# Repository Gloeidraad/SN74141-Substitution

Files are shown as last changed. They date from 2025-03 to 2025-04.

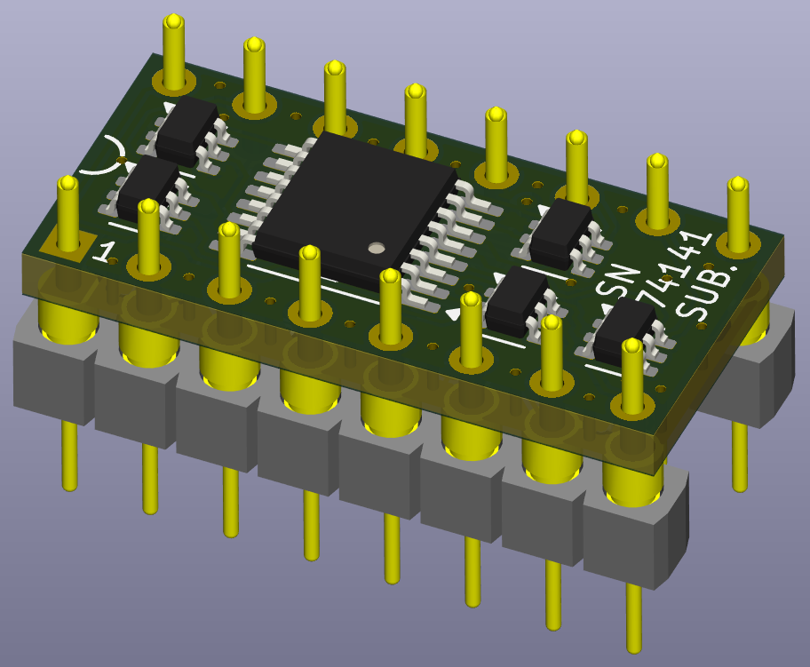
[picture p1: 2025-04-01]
Doc/3d.png

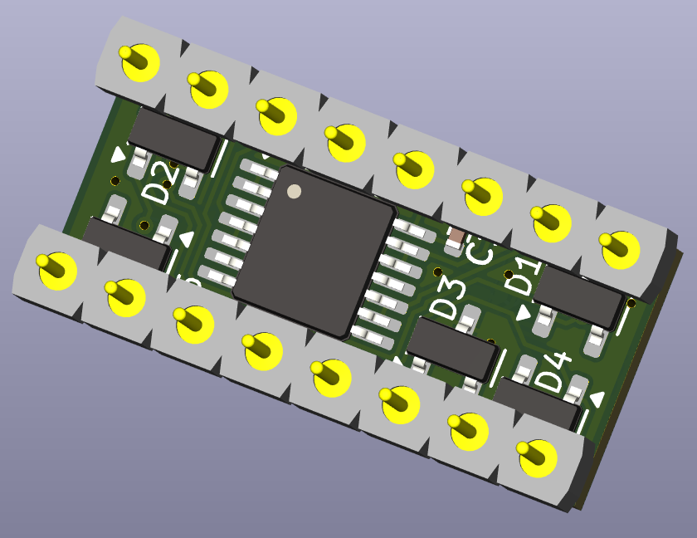
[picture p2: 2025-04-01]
Doc/3d-bot.png

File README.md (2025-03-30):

The SN74141 is an obsolete device intended for diving nixie tubes. However, even today, enthusiasts still love nixie tubes. Sometimes by building digital clocks with nixies, but also keeping vintage equivalent alive. In the old days, very often the nixie tubes are driven by the good old SN74141 device. These devices (or the soviet K155ID1) can still be found on the internet, but stocks are dwindling. I tried to make a replacement circuit which should fit on the location of the original DIL-16 footprint of the SN74141. 

Because of the limited size of the DIL-16 socket, I had to use the smallest devices possible, so if you want to use the design, be sure you are capable to solder TSSOP devices.

The design is not implement on a real PCBA yet, so please test it yourself before placing it in al valuable instrument.

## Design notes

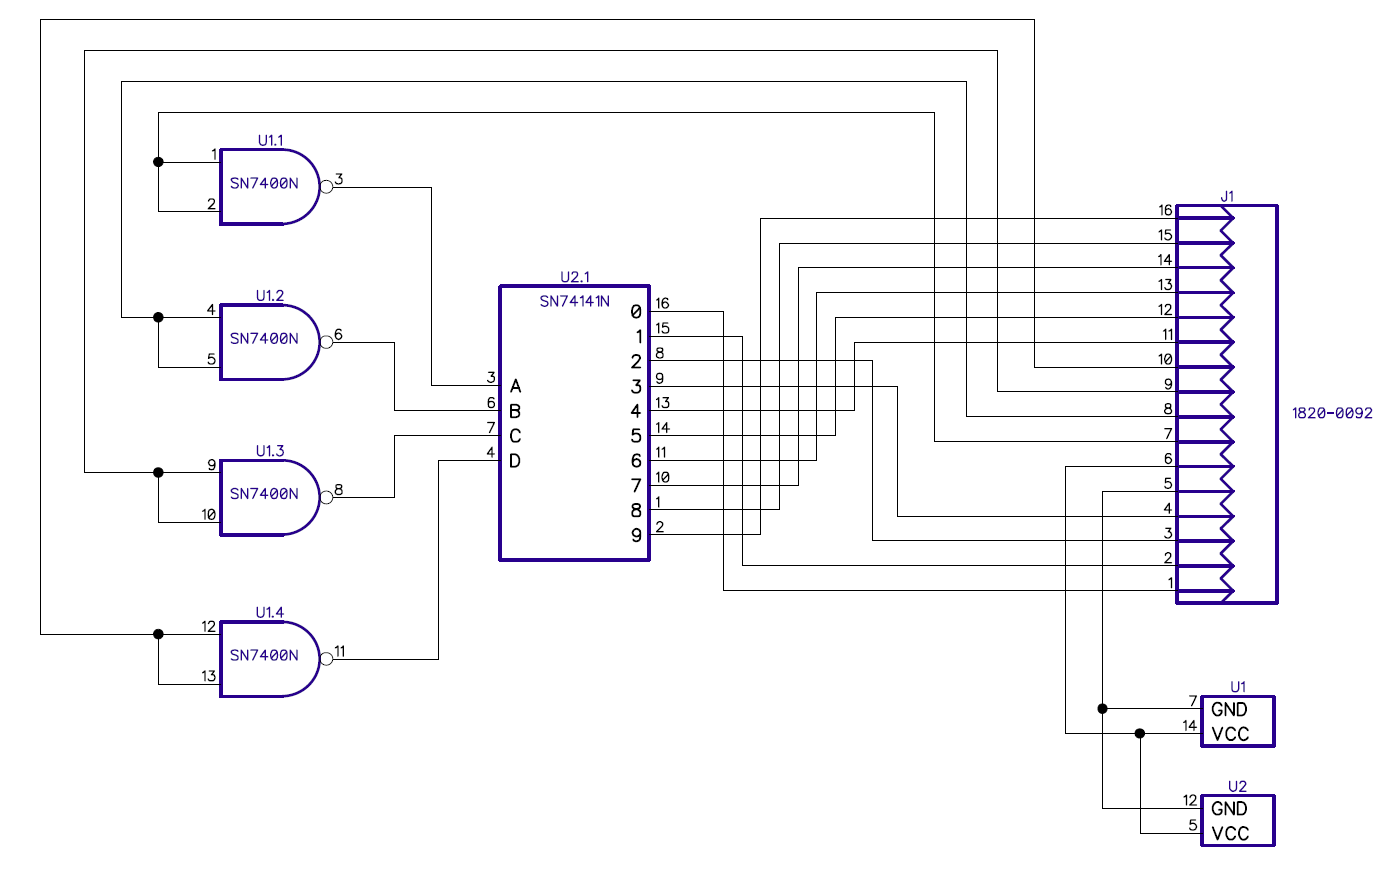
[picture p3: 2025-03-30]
Doc/Schematic 1820-0092.png

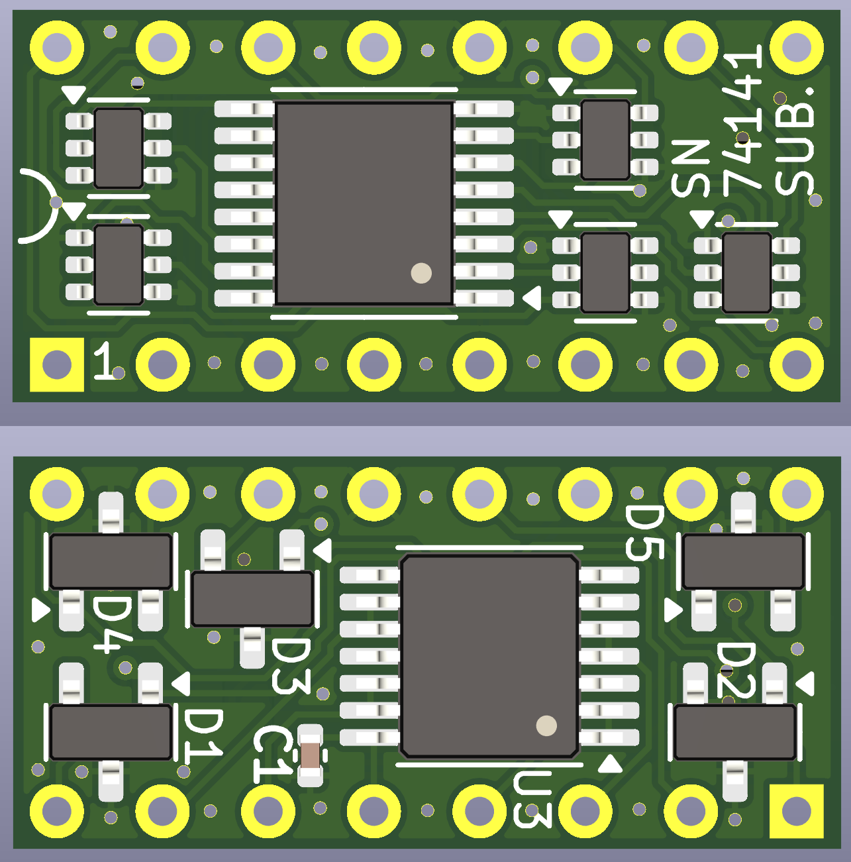
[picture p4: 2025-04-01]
Doc/PCB-V2.png

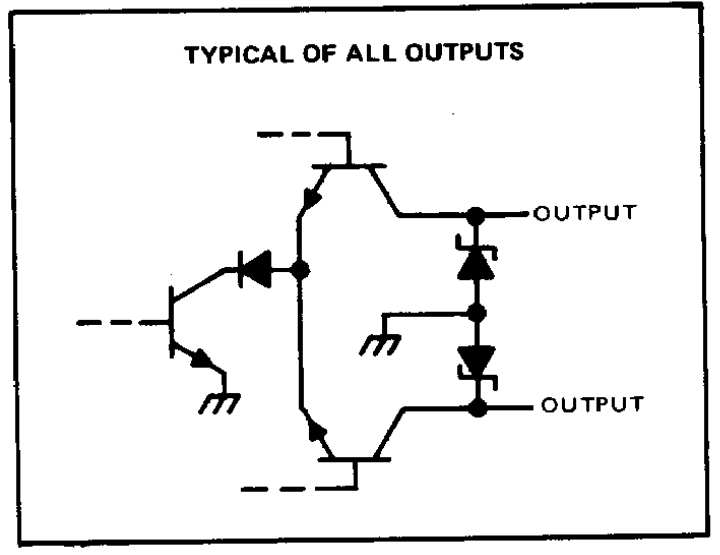
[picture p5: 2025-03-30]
Doc/74141-output.png

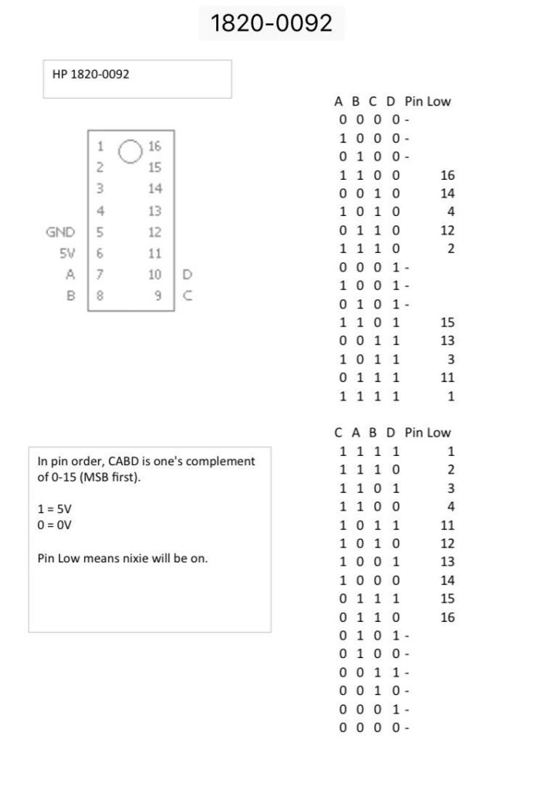
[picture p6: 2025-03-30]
Doc/1820-0092_pins-705x1024.jpg

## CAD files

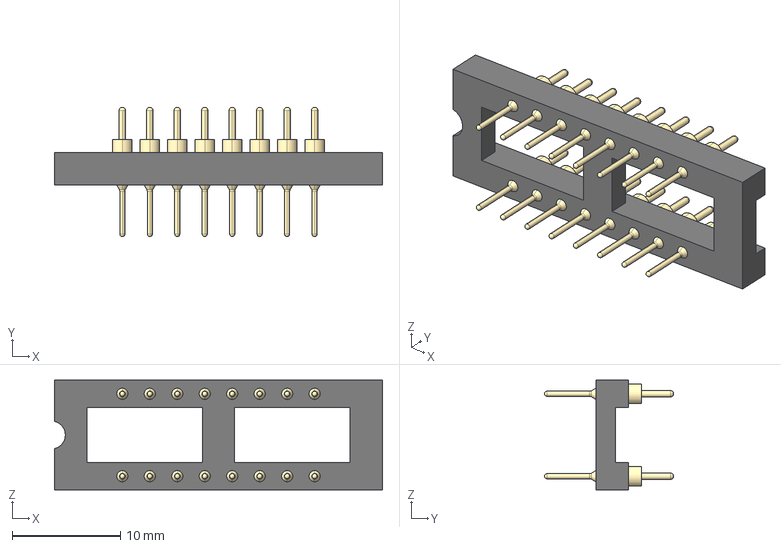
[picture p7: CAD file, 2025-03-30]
Doc/ar_16-st_t.stp
30.3 x 12.0 x 10.2 mm

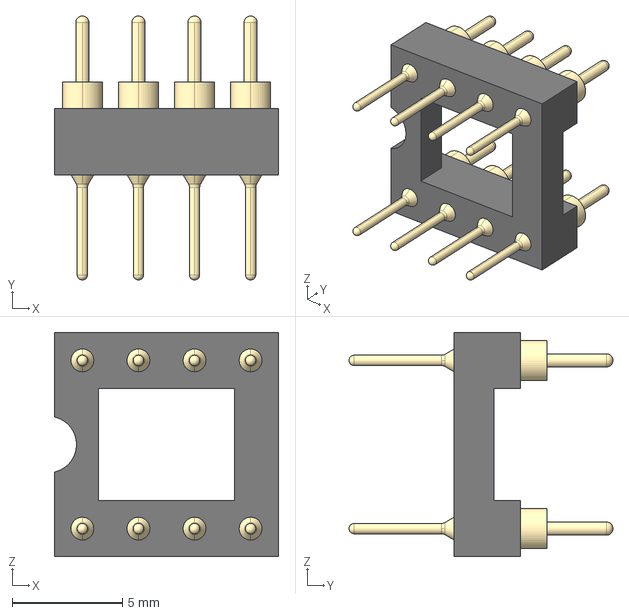
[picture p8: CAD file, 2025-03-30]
Doc/ar_08-st_t.stp
10.2 x 12.0 x 10.2 mm

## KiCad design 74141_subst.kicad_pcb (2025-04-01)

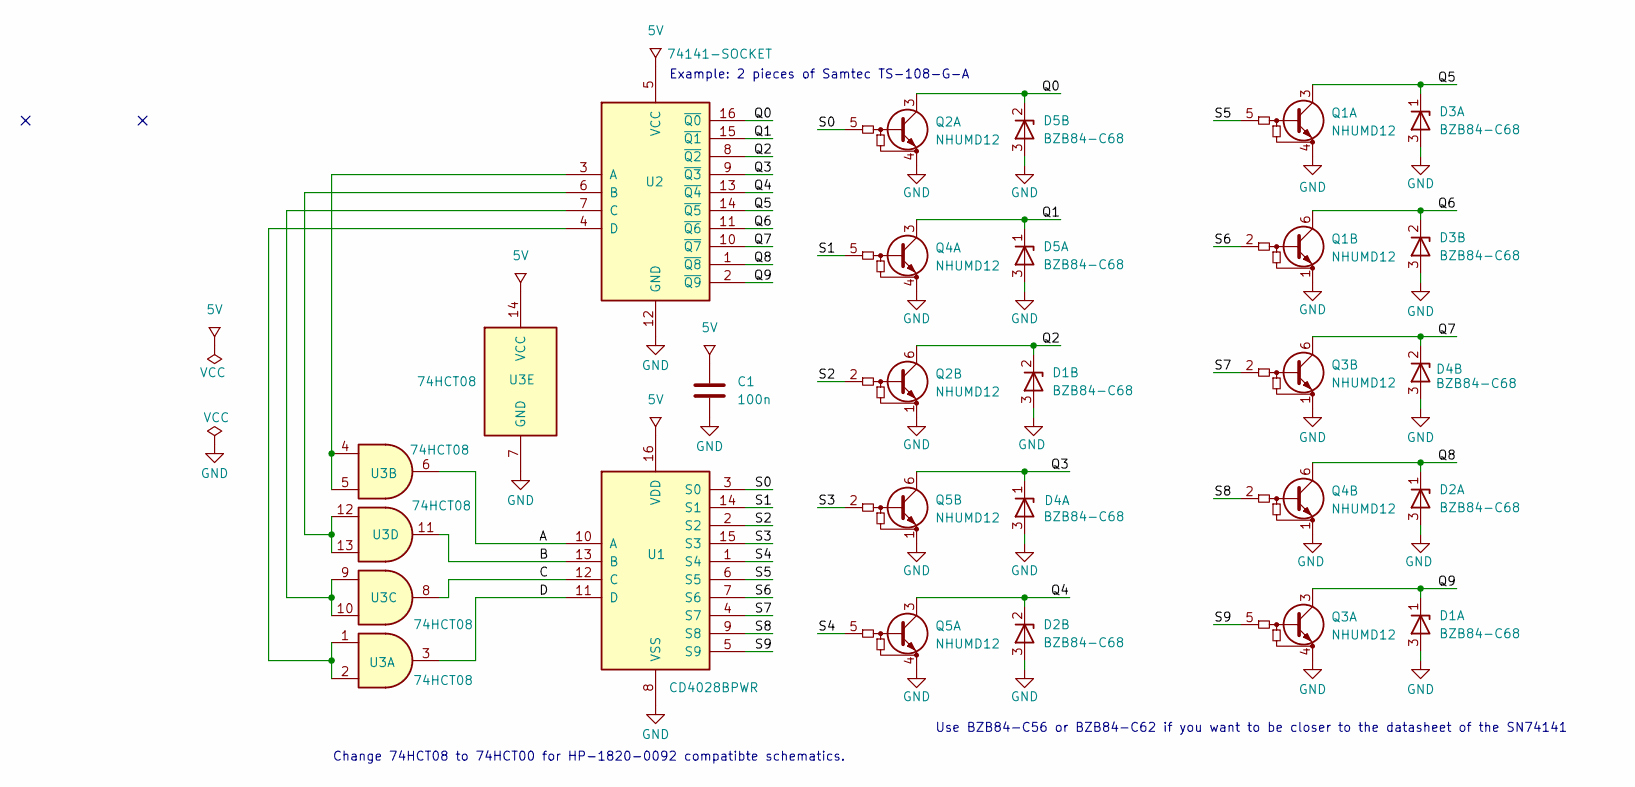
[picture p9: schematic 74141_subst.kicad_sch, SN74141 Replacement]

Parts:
C1: 100n; C_0402_1005Metric
D1, D2, D3, D4, D5: BZB84-C68; SOT-23
Q1, Q2, Q3, Q4, Q5: NHUMD12; SOT-363_SC-70-6
U1: CD4028BPWR; TSSOP-16_4.4x5mm_P0.65mm
U2: 74141-SOCKET; DIP-16-header-type2
U3: 74HCT08; TSSOP-14_4.4x5mm_P0.65mm

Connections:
5V: C1.1, U1.16 (VDD), U2.5 (VCC), U3.14 (VCC)
/A: U1.10 (A), U3.6
/B: U1.13 (B), U3.11
/C: U1.12 (C), U3.8
/D: U1.11 (D), U3.3
/Q0: D5.2 (K), Q2.3 (C1), U2.16 (~Q0)
/Q1: D5.1 (K), Q4.3 (C1), U2.15 (~Q1)
/Q2: D1.2 (K), Q2.6 (C2), U2.8 (~Q2)
/Q3: D4.1 (K), Q5.6 (C2), U2.9 (~Q3)
/Q4: D2.2 (K), Q5.3 (C1), U2.13 (~Q4)
/Q5: D3.1 (K), Q1.3 (C1), U2.14 (~Q5)
/Q6: D3.2 (K), Q1.6 (C2), U2.11 (~Q6)
/Q7: D4.2 (K), Q3.6 (C2), U2.10 (~Q7)
/Q8: D2.1 (K), Q4.6 (C2), U2.1 (~Q8)
/Q9: D1.1 (K), Q3.3 (C1), U2.2 (~Q9)
/S0: Q2.5 (B1), U1.3 (S0)
/S1: Q4.5 (B1), U1.14 (S1)
/S2: Q2.2 (B2), U1.2 (S2)
/S3: Q5.2 (B2), U1.15 (S3)
/S4: Q5.5 (B1), U1.1 (S4)
/S5: Q1.5 (B1), U1.6 (S5)
/S6: Q1.2 (B2), U1.7 (S6)
/S7: Q3.2 (B2), U1.4 (S7)
/S8: Q4.2 (B2), U1.9 (S8)
/S9: Q3.5 (B1), U1.5 (S9)
GND: C1.2, D1.3 (A), D2.3 (A), D3.3 (A), D4.3 (A), D5.3 (A), Q1.1 (E2), Q1.4 (E1), Q2.1 (E2), Q2.4 (E1), Q3.1 (E2), Q3.4 (E1), Q4.1 (E2), Q4.4 (E1), Q5.1 (E2), Q5.4 (E1), U1.8 (VSS), U2.12 (GND), U3.7 (GND)
unnamed: U2.3 (A), U3.4, U3.5
unnamed: U2.6 (B), U3.12, U3.13
unnamed: U2.7 (C), U3.9, U3.10
unnamed: U2.4 (D), U3.1, U3.2

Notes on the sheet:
Example: 2 pieces of Samtec TS-108-G-A
Use BZB84-C56 or BZB84-C62 if you want to be closer to the datasheet of the SN74141
Change 74HCT08 to 74HCT00 for HP-1820-0092 compatibte schematics.

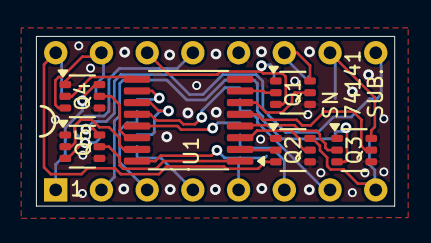
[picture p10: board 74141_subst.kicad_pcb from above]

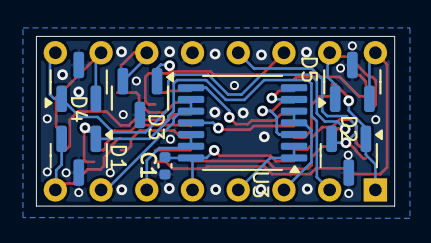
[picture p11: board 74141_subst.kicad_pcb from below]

Board: 2 copper layers, 19.9 x 9.4 mm, 14 parts (7 on the bottom side), 30 nets.

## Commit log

2025-04-01 Added info in silk
    [74141_subst.kicad_pcb, 74141_subst.kicad_sch]
2026-07-25 Changed high voltage drivers to MMDTA42
2026-11-08 Added optional zener protection sub assembly
